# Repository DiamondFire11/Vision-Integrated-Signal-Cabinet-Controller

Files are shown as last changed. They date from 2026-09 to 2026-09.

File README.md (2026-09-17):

# Vision-Integrated Signal Cabinet Controller | SAMD21 24V Traffic Interconnect








An industrial hardware bridge interfacing edge computer vision point-cloud object detection models with CALTRANS-compliant 24V DC intersection signal controllers. Powered by an extended-temperature SAMD21 32-bit ARM Cortex-M0+ MCU, the board translates real-time inference commands into galvanically isolated 24V signal toggles using custom zero-allocation C++ dual state machines and power-of-two ring buffer memory architectures.

---

## 📷 System Architecture & PCB Render

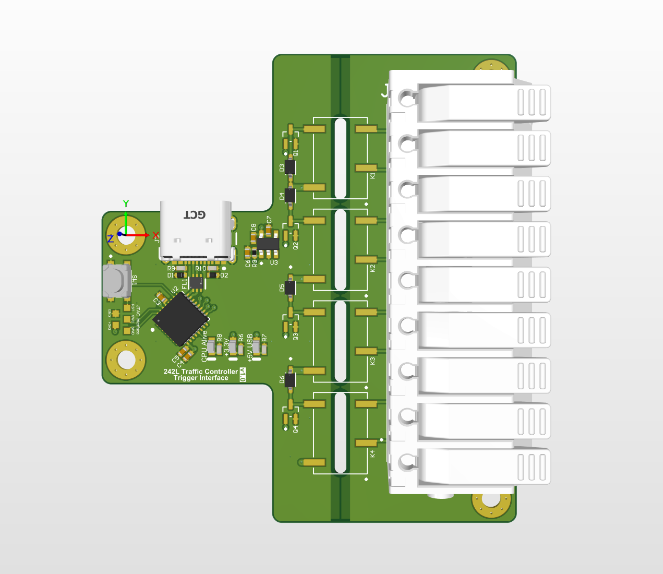
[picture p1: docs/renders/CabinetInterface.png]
Signal Cabinet Interface Render


---

## 🛠 Engineering Highlights & System Architecture

* **Galvanically Isolated 24V Industrial I/O:** Bridges 3.3V MCU logic to high-voltage CALTRANS intersection cabinets via 4 channels of low-power signal relays, preventing high-voltage transients from affecting inference hardware.
* **Dual non-blocking C++ State Machines:** Decouples serial command parsing from physical GPIO actuation. A Serial SM processes incoming ASCII inference streams while a deterministic Channel Driver SM handles timing and relay state execution.
* **Zero-Allocation Ring Buffer Architecture:** Encapsulates channel state in a `ChannelManager` class using power-of-two ring buffers ($2^n$). Leverages bitwise bitmask operations (`index & (SIZE - 1)`) instead of modulo operations to guarantee zero-latency buffer bounds enforcement.
* **Atomic Bit-Field State Tracking & Re-trigger Handling:** Uses an 8-bit `ticket` status variable split into Request (lower 4 bits) and Active (upper 4 bits) flags. Re-trigger spam from edge vision models automatically resets activation timers without dropping relay state, returning real-time ASCII telemetry back to the vision node.
* **Extended Thermal Rating:** Fully populated with industrial/extended-temperature-rated ICs and relays (-40°C to +85°C) engineered for unconditioned roadside cabinet environments.
---

## 📐 System Technical Specifications

| Parameter | Specification Details |
| :--- | :--- |
| **Microcontroller** | Microchip/Atmel SAMD21E18 (Industrial Extended-Temp Rating) |
| **Cabinet Interface Voltage** | 24V DC Digital Logic (CALTRANS TEES Interconnect Standard) |
| **Relay Isolation Stage** | 4-Channel Galvanic Signal Relays (Optically / Electromechanically Isolated) |
| **Host Communication** | USB 2.0 CDC Virtual COM (ASCII Command/Telemetry Protocol) |
| **Memory Management** | Fixed Allocation $2^n$ Static Ring Buffer with Bitwise Masking |
| **State Synchronization** | Atomic 8-Bit Ticket State Variable (Upper 4: Active / Lower 4: Requested) |
| **Operating Environment** | Extended Industrial Temperature Range (-40°C to +85°C) |

---

## 🔬 Validation, Testing & Debugging

* **Industrial Transient Protection:** Validated galvanic isolation boundary across 24V switching loads to ensure zero ground loops or inductive feedback into the SAMD21 host MCU.
* **Relay Re-triggering Logic Verification:** Tested edge-case serial input spamming from the CV host; confirmed that active channels safely reset `time_activated` without output chatter or state desynchronization.
* **Real-Time ASCII Telemetry Benchmarking:** Measured low-latency serial parsing loops and confirmed deterministic timing under max baud-rate synthetic vision detection bursts.

---

## ⚙️ Software Architecture & Dynamic State Flow

```text
[ CV Point-Cloud Model ] 
       │ (ASCII Commands over USB Serial)
       ▼
┌─────────────────────────────────────────────────────────┐
│  Serial State Machine                                   │
│  - Parses incoming serial buffer                        │
│  - Sets Request Bits in 8-bit Ticket Register           │
│  - Emits telemetry & channel reset warnings             │
└────────────────────────────┬────────────────────────────┘
                             │ Writes to
                             ▼
┌─────────────────────────────────────────────────────────┐
│  ChannelManager (Ring Buffer)                           │
│  - Holds Channel structs (ID, Time Activated, Duration) │
│  - Evaluated using bitwise masking ops (& MASK)         │
└────────────────────────────┬────────────────────────────┘
                             │ Reads from
                             ▼
┌─────────────────────────────────────────────────────────┐
│  GPIO Channel Driver State Machine                      │
│  - Sets Active Bits in upper half of Ticket Register    │
│  - Drives Galvanically Isolated 24V Signal Relays       │
└────────────────────────────┬────────────────────────────┘
                             │ Toggles
                             ▼
[ Caltrans 24V DC Intersection Cabinet ]
```

---

## 💻 Firmware Architecture & Flashing

The firmware utilizes a custom PlatformIO board variant forked from the `Adafruit Arduino SAMD Core` to map the custom PCB pin configuration correctly.

```bash
# Clone the repository
git clone https://github.com/DiamondFire11/Traffic-Signal-Interconnect.git
cd Cabinet-Signal-Interface

# Build firmware target via PlatformIO
pio run -e samd21_cabinet_interface
```

---

## ⚡ Flashing via SWD & Hardware Debugging
1. Connect an Atmel-ICE or SWD-compatible programmer to the target SWD header pads.
2. Flash the board configuration using PlatformIO or Atmel Studio.
3. **Recovery Mode**: If USB SERCOM arbitration triggers a bus fault during firmware execution, double-tap the physical reset pad to force hardware bootloader mode.

--- 

## 📄 License & Hardware Manufacturing Files
* **Production Files**: Production Gerber (.gbr), N.C. Drill (.drl), Solder Paste Stencils (.gtp/.gbp), and Altium Draftsman assembly drawings are located in the /hardware directory
* **License**: Distributed under [GPLv3 License](https://github.com/DiamondFire11/Tartarus-Joystick-Mod/blob/main/LICENSE).

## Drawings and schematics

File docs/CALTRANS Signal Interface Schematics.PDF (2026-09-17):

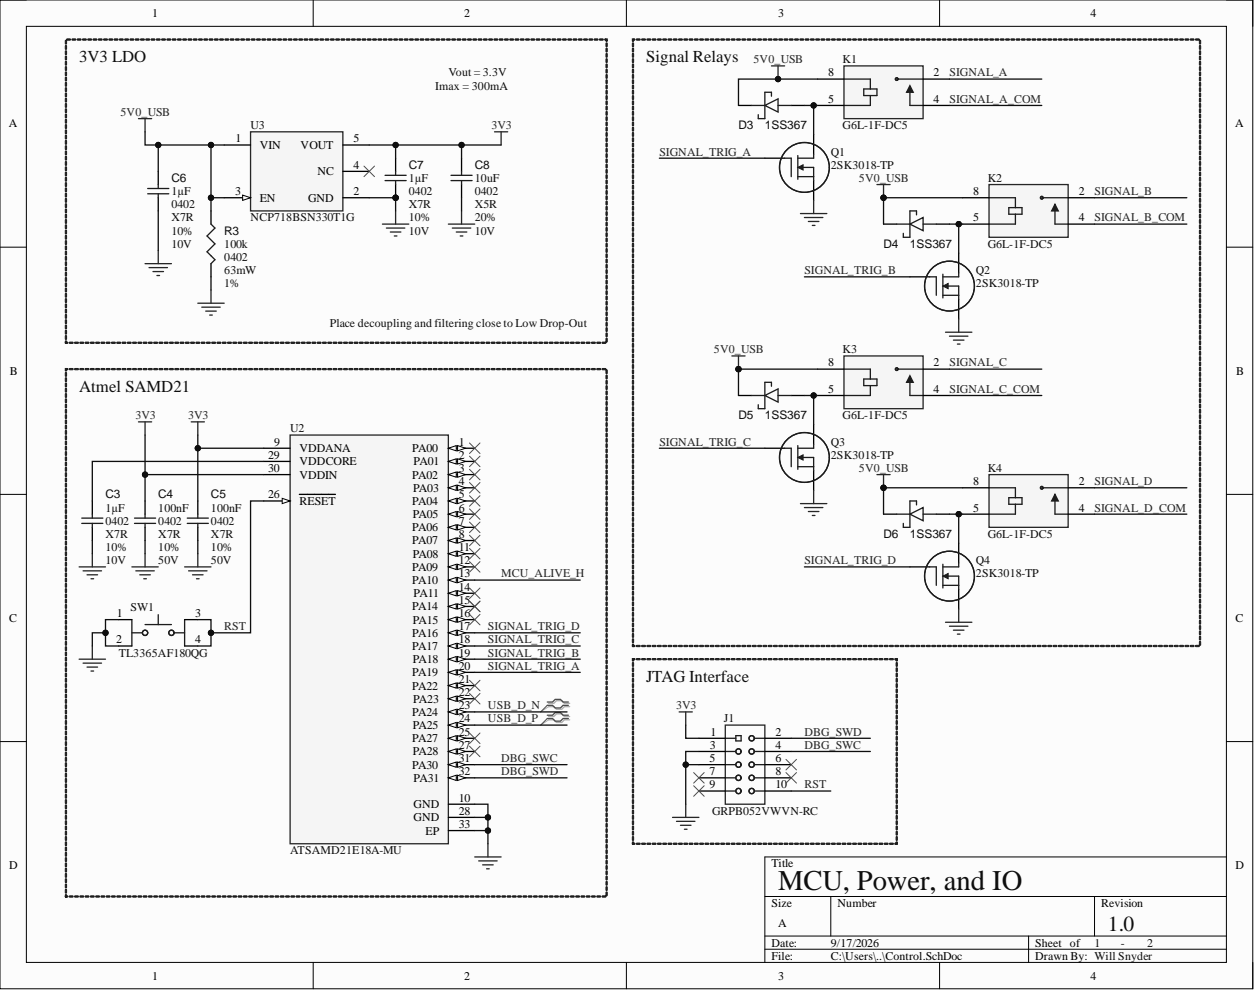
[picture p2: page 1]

Place decoupling and filtering close to Low Drop-Out

VDDCORE 29

C3 | VDDIN 30

100nF 0402 X7R 10% 50V RST

Title
MCU, Power, and IO

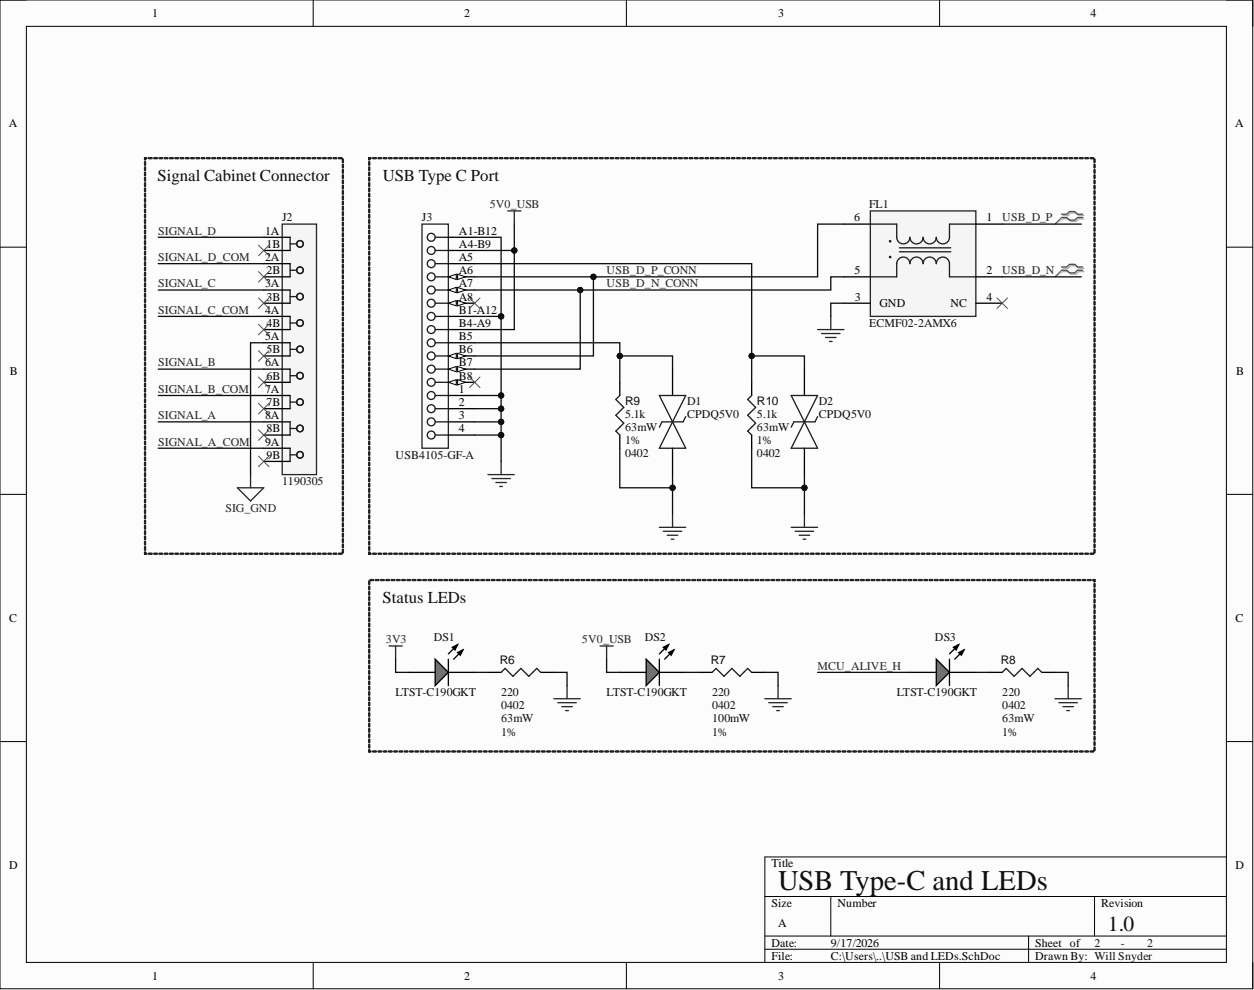
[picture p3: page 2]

Title
USB Type-C and LEDs

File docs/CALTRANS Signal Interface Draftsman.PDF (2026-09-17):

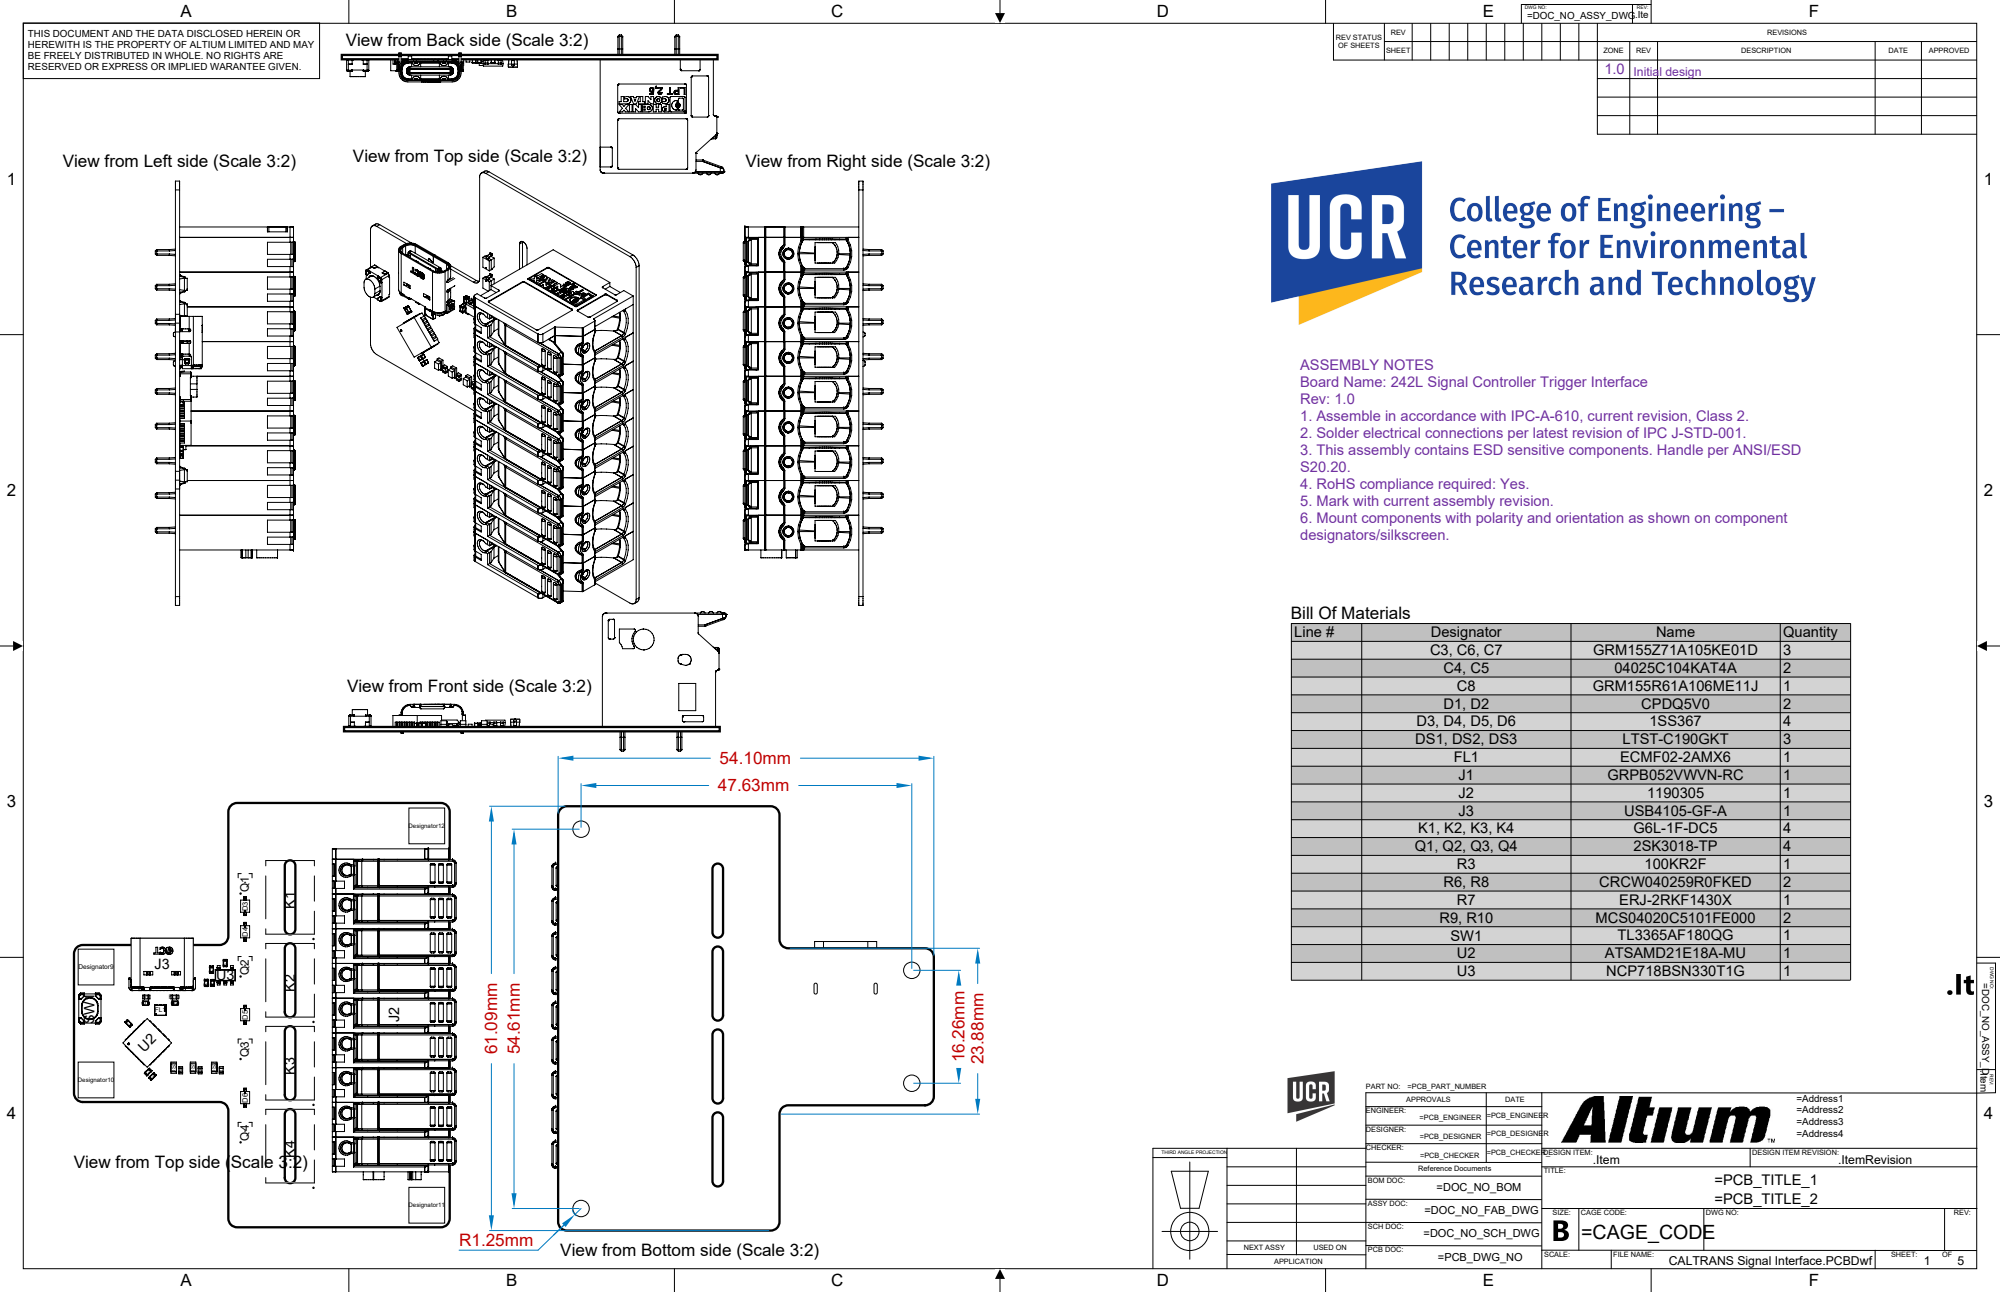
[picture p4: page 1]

HEREWITH IS THE PROPERTY OF ALTIUM LIMITED AND MAY
BE FREELY DISTRIBUTED IN WHOLE. NO RIGHTS ARE
RESERVED OR EXPRESS OR IMPLIED WARANTEE GIVEN.

View from Back side (Scale 3:2)

View from Top side (Scale 3:2)

ASSEMBLY NOTES
Board Name: 242L Signal Controller Trigger Interface
Rev: 1.0
1. Assemble in accordance with IPC-A-610, current revision, Class 2.
2. Solder electrical connections per latest revision of IPC J-STD-001.
3. This assembly contains ESD sensitive components. Handle per ANSI/ESD
4. RoHS compliance required: Yes.
5. Mark with current assembly revision.
6. Mount components with polarity and orientation as shown on component
designators/silkscreen.

Line # | Designator | Name | Quantity

C3, C6, C7 | GRM155Z71A105KE01D | 3
C4, C5 | 04025C104KAT4A | 2
C8 | GRM155R61A106ME11J | 1
D1, D2 | CPDQ5V0 | 2
D3, D4, D5, D6 | 1SS367 | 4
DS1, DS2, DS3 | LTST-C190GKT | 3
FL1 | ECMF02-2AMX6 | 1
J1 | GRPB052VWVN-RC | 1
J2 | 1190305 | 1
J3 | USB4105-GF-A | 1
K1, K2, K3, K4 | G6L-1F-DC5 | 4
Q1, Q2, Q3, Q4 | 2SK3018-TP | 4
R3 | 100KR2F | 1
R6, R8 | CRCW040259R0FKED | 2
R7 | ERJ-2RKF1430X | 1
R9, R10 | MCS04020C5101FE000 | 2
SW1 | TL3365AF180QG | 1
U2 | ATSAMD21E18A-MU | 1
U3 | NCP718BSN330T1G | 1

View from Front side (Scale 3:2)

APPROVALS | DATE

ENGINEER: =PCB_ENGINEER

DESIGNER: =PCB_DESIGNER

THIRD ANGLE PROJECTION

CHECKER: =PCB_CHECKER | =PCB_CHECKER_

SCH DOC: =DOC_NO_SCH_DWG

View from Bottom side (Scale 3:2)

NEXT ASSY | USED ON

CALTRANS Signal Interface.PCBDwf

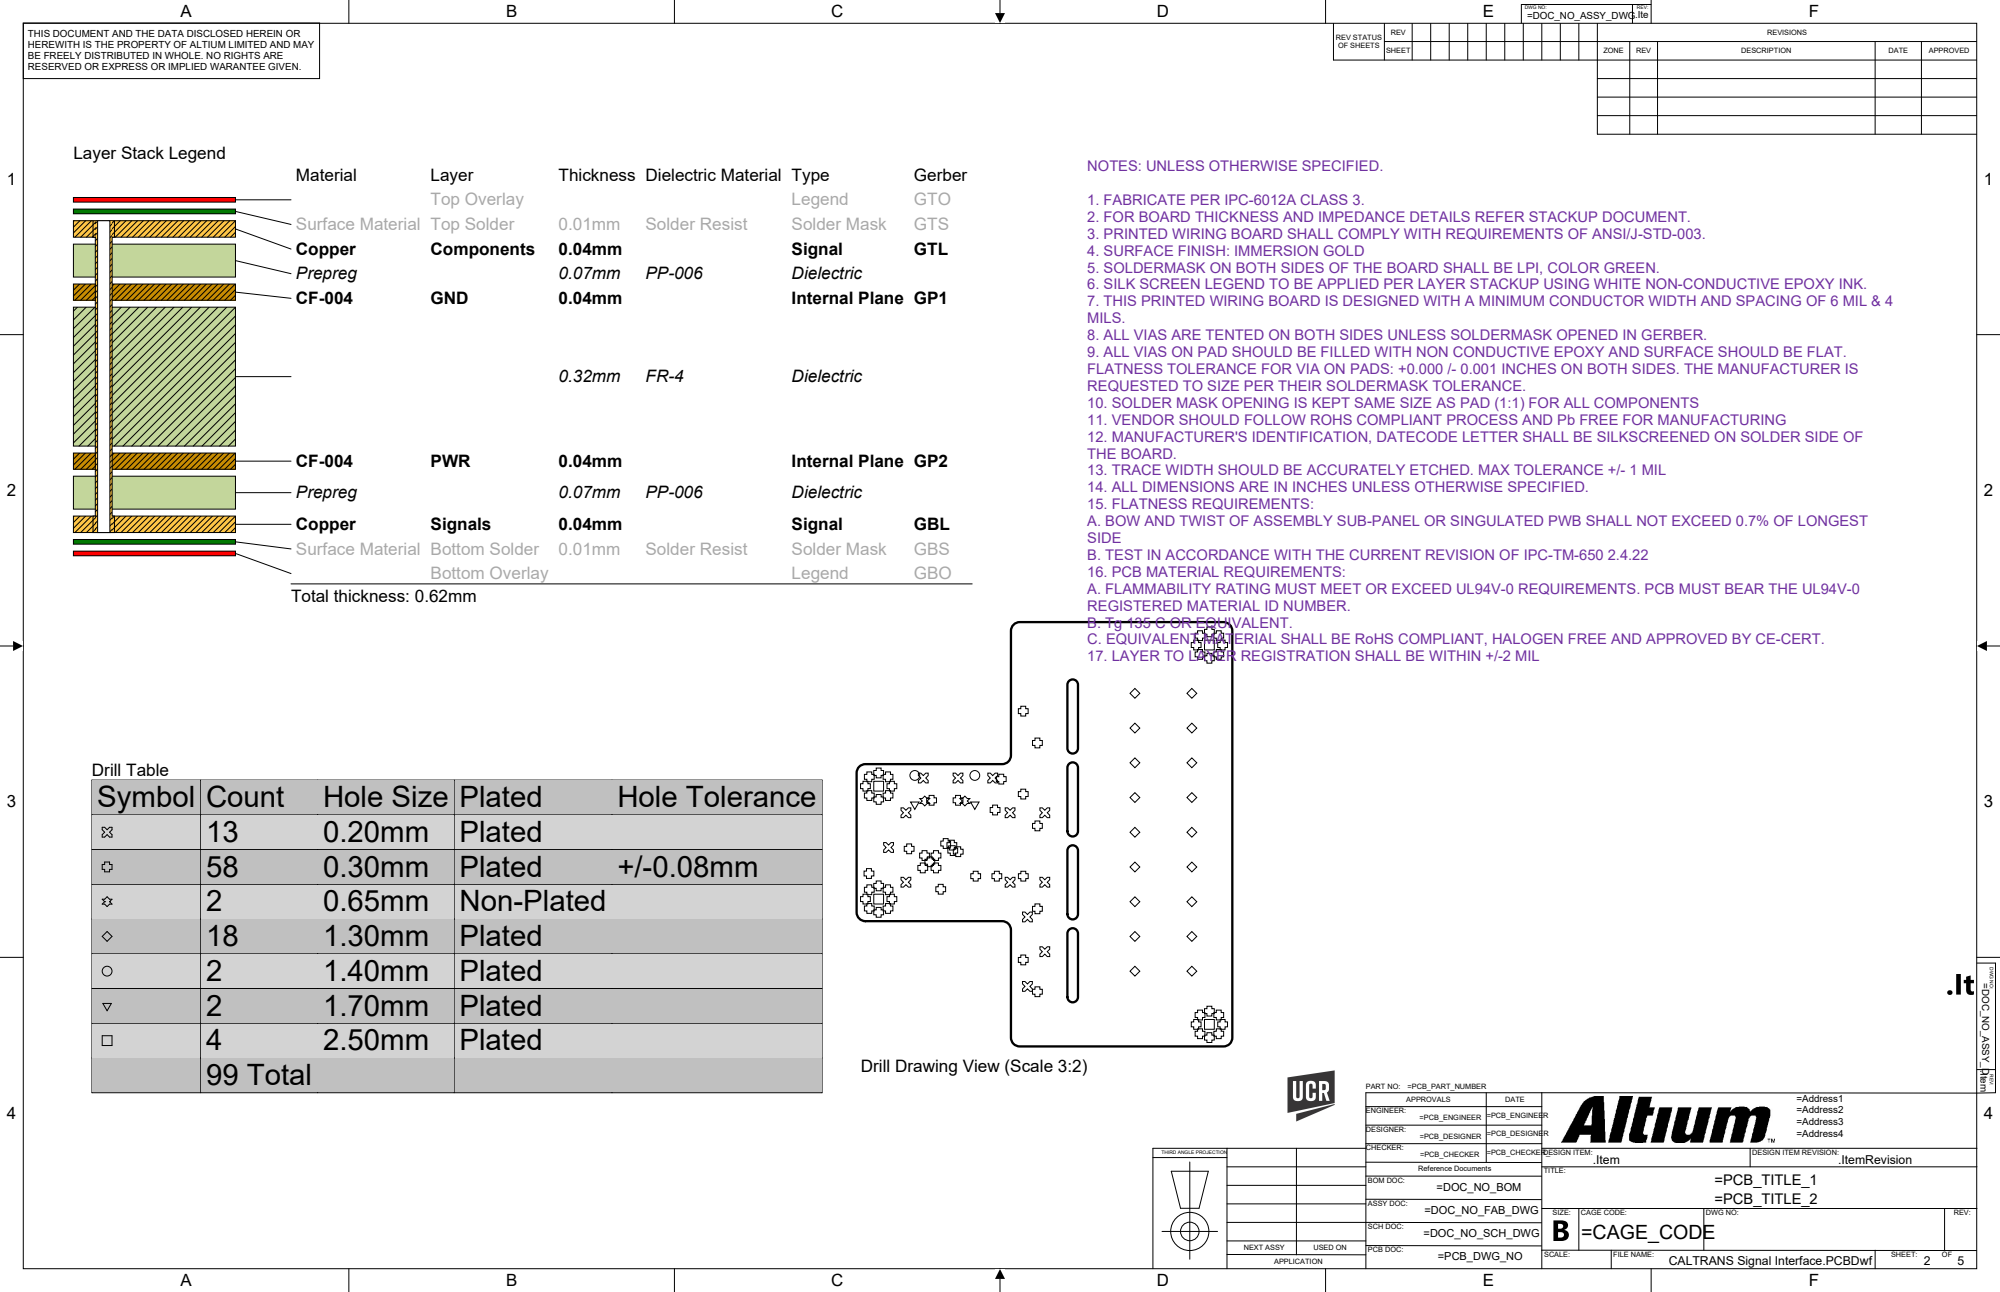
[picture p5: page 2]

NOTES: UNLESS OTHERWISE SPECIFIED.

1. FABRICATE PER IPC-6012A CLASS 3.
2. FOR BOARD THICKNESS AND IMPEDANCE DETAILS REFER STACKUP DOCUMENT.
3. PRINTED WIRING BOARD SHALL COMPLY WITH REQUIREMENTS OF ANSI/J-STD-003.
4. SURFACE FINISH: IMMERSION GOLD
5. SOLDERMASK ON BOTH SIDES OF THE BOARD SHALL BE LPI, COLOR GREEN.
6. SILK SCREEN LEGEND TO BE APPLIED PER LAYER STACKUP USING WHITE NON-CONDUCTIVE EPOXY INK.
7. THIS PRINTED WIRING BOARD IS DESIGNED WITH A MINIMUM CONDUCTOR WIDTH AND SPACING OF 6 MIL & 4
MILS.
8. ALL VIAS ARE TENTED ON BOTH SIDES UNLESS SOLDERMASK OPENED IN GERBER.
9. ALL VIAS ON PAD SHOULD BE FILLED WITH NON CONDUCTIVE EPOXY AND SURFACE SHOULD BE FLAT.
FLATNESS TOLERANCE FOR VIA ON PADS: +0.000 /- 0.001 INCHES ON BOTH SIDES. THE MANUFACTURER IS
REQUESTED TO SIZE PER THEIR SOLDERMASK TOLERANCE.
10. SOLDER MASK OPENING IS KEPT SAME SIZE AS PAD (1:1) FOR ALL COMPONENTS
11. VENDOR SHOULD FOLLOW ROHS COMPLIANT PROCESS AND Pb FREE FOR MANUFACTURING
12. MANUFACTURER'S IDENTIFICATION, DATECODE LETTER SHALL BE SILKSCREENED ON SOLDER SIDE OF
THE BOARD.
13. TRACE WIDTH SHOULD BE ACCURATELY ETCHED. MAX TOLERANCE +/- 1 MIL
14. ALL DIMENSIONS ARE IN INCHES UNLESS OTHERWISE SPECIFIED.
15. FLATNESS REQUIREMENTS:
A. BOW AND TWIST OF ASSEMBLY SUB-PANEL OR SINGULATED PWB SHALL NOT EXCEED 0.7% OF LONGEST
SIDE
B. TEST IN ACCORDANCE WITH THE CURRENT REVISION OF IPC-TM-650 2.4.22
16. PCB MATERIAL REQUIREMENTS:
A. FLAMMABILITY RATING MUST MEET OR EXCEED UL94V-0 REQUIREMENTS. PCB MUST BEAR THE UL94V-0
REGISTERED MATERIAL ID NUMBER.
B. Tg 135 C OR EQUIVALENT.
C. EQUIVALENT MATERIAL SHALL BE RoHS COMPLIANT, HALOGEN FREE AND APPROVED BY CE-CERT.
17. LAYER TO LAYER REGISTRATION SHALL BE WITHIN +/-2 MIL

Symbol | Count | Hole Size | Plated | Hole Tolerance

13 | 0.20mm | Plated
58 | 0.30mm | Plated | +/-0.08mm
2 | 0.65mm | Non-Plated
18 | 1.30mm | Plated
2 | 1.40mm | Plated
2 | 1.70mm | Plated
4 | 2.50mm | Plated
99 Total

Drill Drawing View (Scale 3:2)

APPROVALS | DATE

ENGINEER: =PCB_ENGINEER

DESIGNER: =PCB_DESIGNER

THIRD ANGLE PROJECTION

CHECKER: =PCB_CHECKER | =PCB_CHECKER_

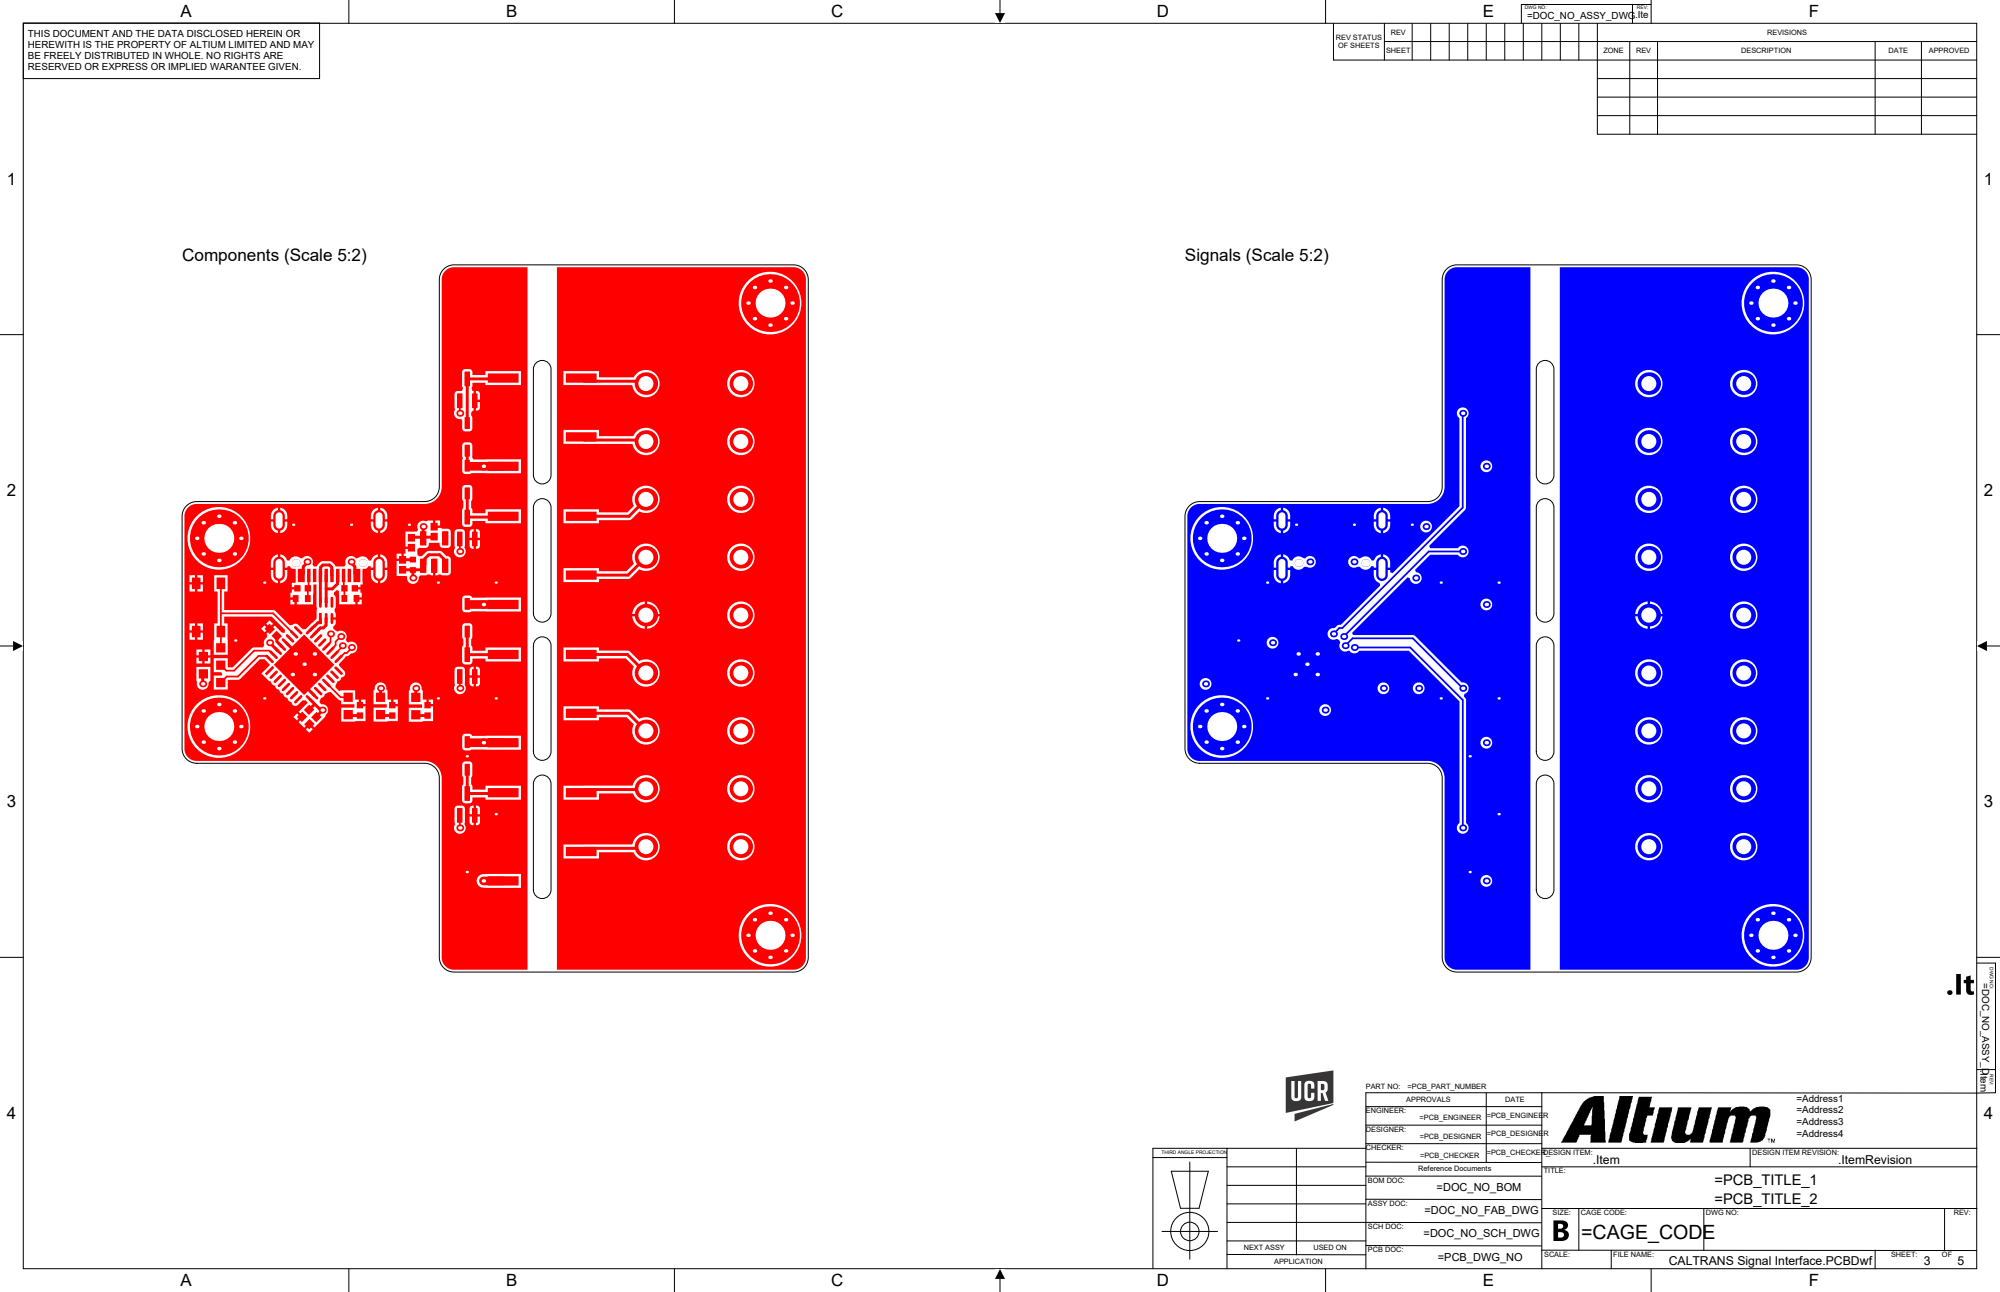
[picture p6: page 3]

APPROVALS | DATE

ENGINEER: =PCB_ENGINEER

DESIGNER: =PCB_DESIGNER

THIRD ANGLE PROJECTION

CHECKER: =PCB_CHECKER | =PCB_CHECKER_

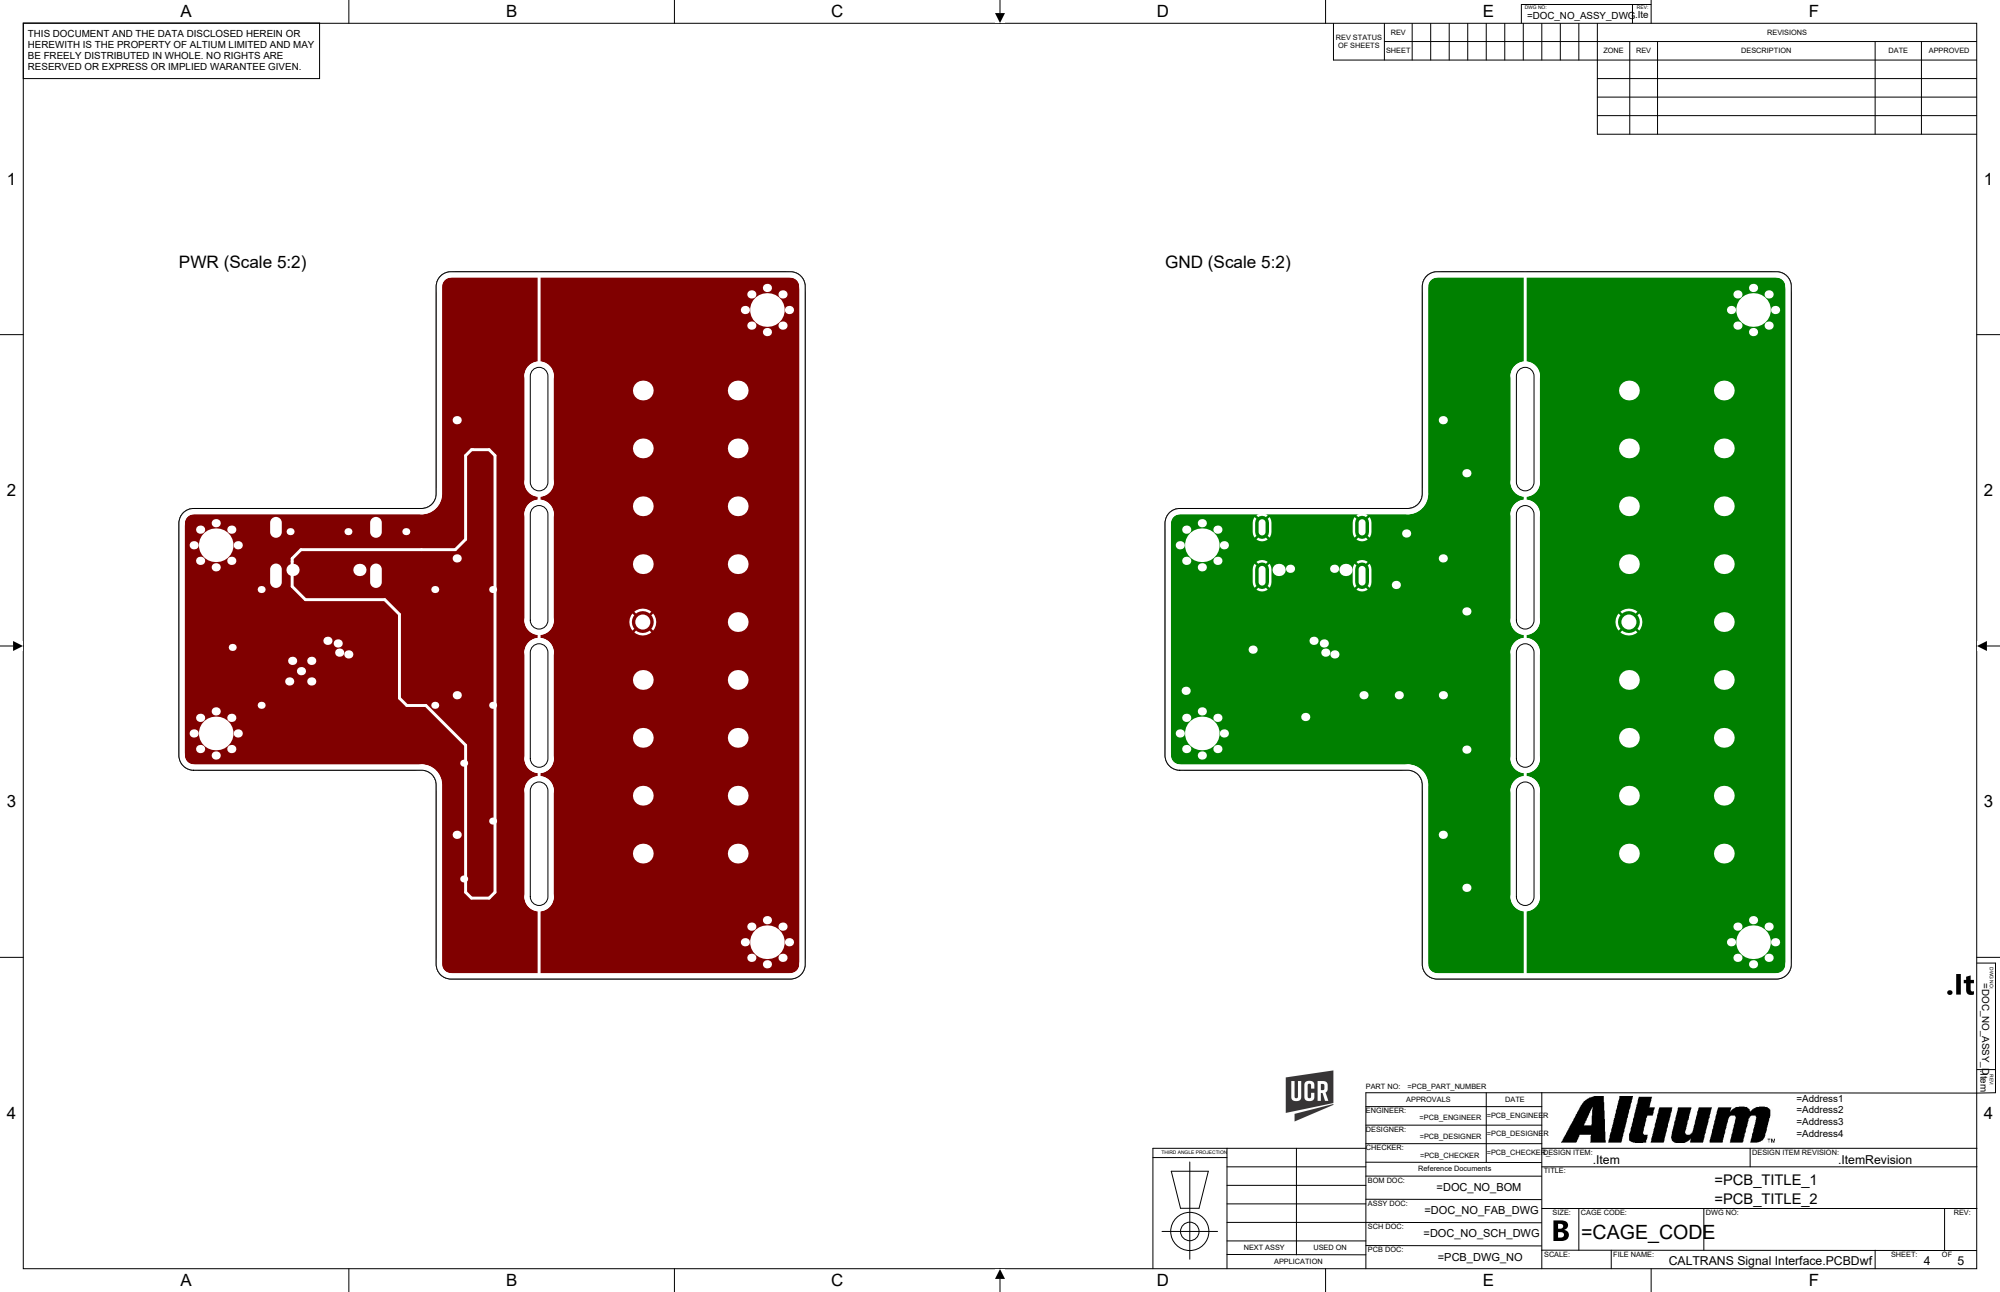
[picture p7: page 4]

APPROVALS | DATE

ENGINEER: =PCB_ENGINEER

DESIGNER: =PCB_DESIGNER

THIRD ANGLE PROJECTION

CHECKER: =PCB_CHECKER | =PCB_CHECKER_

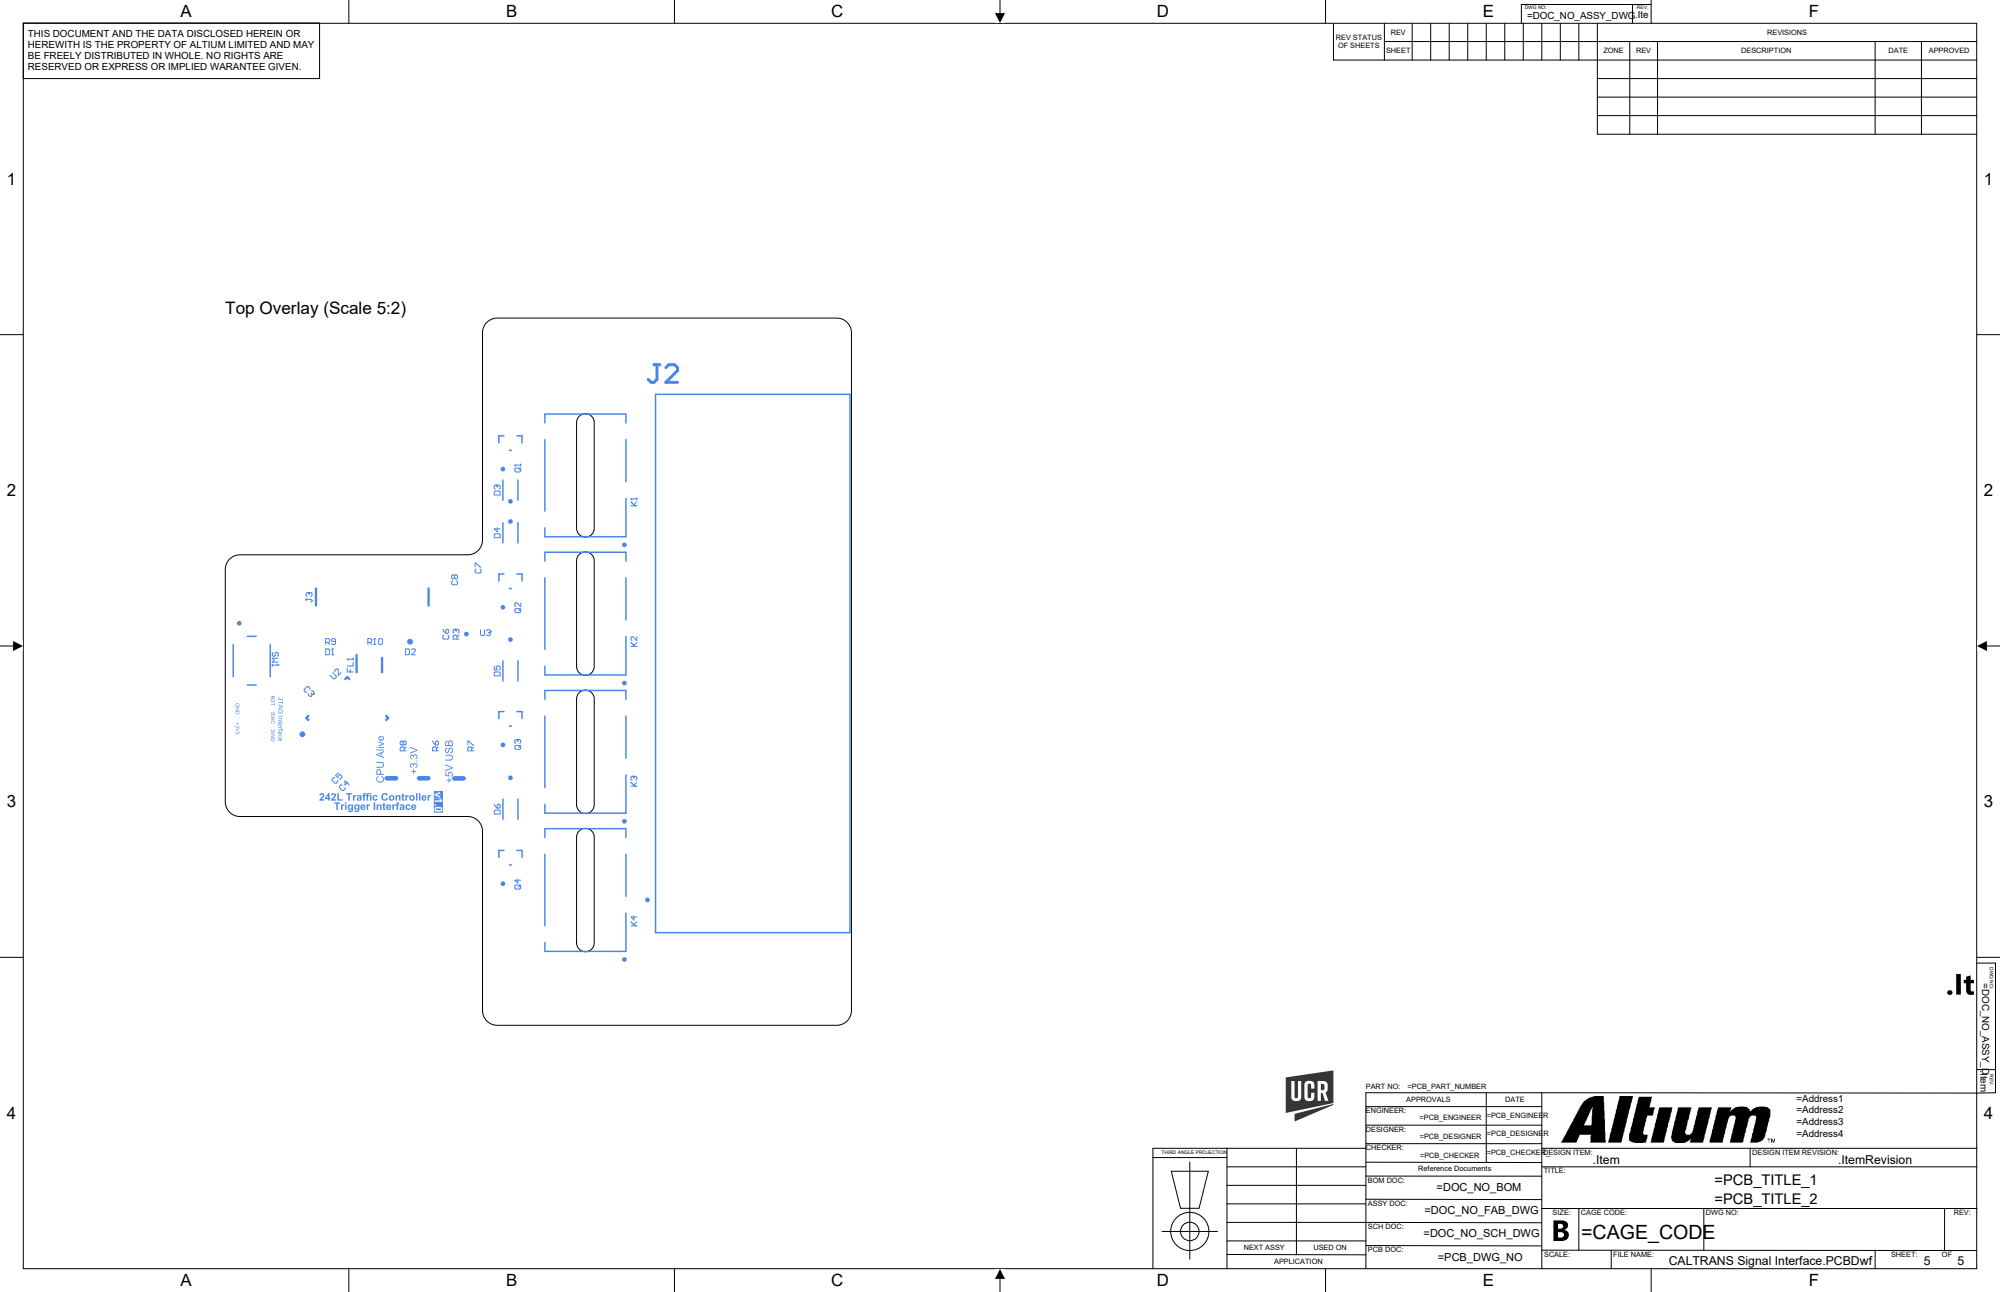
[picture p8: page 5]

APPROVALS | DATE

ENGINEER: =PCB_ENGINEER

DESIGNER: =PCB_DESIGNER

THIRD ANGLE PROJECTION

CHECKER: =PCB_CHECKER | =PCB_CHECKER_

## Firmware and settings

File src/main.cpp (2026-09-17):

#include "../include/ChannelManager.h"
#include "../include/ledFSM.h"
#include "../include/serialReadFSM.h"
#include "../include/relayFSM.h"

#define FW_VERSION "v1.0.1-ringfix " __DATE__ " " __TIME__

struct Tasks {
    uint8_t state;
    uint32_t period;
    uint32_t elapsedTime;
    uint8_t (*tickFcn) (uint8_t);
} typedef Tasks;

Tasks tasks[3]; // Array storing FSMs

ChannelManager manager;

void setup() {
    constexpr uint8_t pins[] = {LED_BUILTIN, CH1, CH2, CH3, CH4};
    for(const uint_fast8_t pin : pins){
        pinMode(pin, OUTPUT);
    }

    digitalWrite(LED_BUILTIN, HIGH);
    Serial.begin(115200);

    // Init LED (CPU Alive) state machine
    tasks[0].state = LED_INIT;
    tasks[0].period = 500;
    tasks[0].elapsedTime = 0;
    tasks[0].tickFcn = &ledTick;

    tasks[1].state = RUN;
    tasks[1].period = 10;
    tasks[1].elapsedTime = 0;
    tasks[1].tickFcn = &readTick;

    tasks[2].state = LOOP;
    tasks[2].period = 10;
    tasks[2].elapsedTime = 0;
    tasks[2].tickFcn = &relayTick;
}

void loop() {
    for (auto & task : tasks) {
        if (millis() - task.elapsedTime >= task.period) {
            task.state = task.tickFcn(task.state);
            task.elapsedTime = millis(); // Last time this task was ran
        }
    }
}

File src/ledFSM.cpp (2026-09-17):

#include "../include/ledFSM.h"

uint8_t ledTick(uint8_t state) {
    state = ledTransition(state);
    ledAction(state);
    return state;
}

uint8_t ledTransition(uint8_t state) {
    switch (state) {
        case LED_INIT:
        case ON:
            state = OFF;
            break;

        case OFF:
            state = ON;
            break;

        default:
            Serial.println("Error: Encountered unknown state, resetting SM.");
            state = LED_INIT;
    }
    return state;
}

void ledAction(const uint8_t state) {
    switch (state) {
        case LED_INIT:
        case OFF:
            digitalWrite(LED_BUILTIN, LOW);
            break;

        case ON:
            digitalWrite(LED_BUILTIN, HIGH);
            break;

        default:
            digitalWrite(LED_BUILTIN, LOW);
    }
}

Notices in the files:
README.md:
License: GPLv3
